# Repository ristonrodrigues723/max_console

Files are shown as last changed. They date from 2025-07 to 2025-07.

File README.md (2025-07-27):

This is my latest project: a Raspberry Pi Zero 2 W-based console running on RetroPie. I've optimized the Bill of Materials (BOM) to include the best and cheapest available items from official retailers for the Raspberry Pi and screen.
When overclocked(necessary for psp), this console should be able to emulate most systems, including Nintendo DS, Game Boy Advance (GBA), Game Boy Color (GBC), PlayStation (PSX), and even some (PSP games.
I am currently setting up the code for the buttons. My design incorporates 18-20 buttons, similar to a PSP, allowing for accurate emulation of those games. By utilizing the Adafruit button script for RetroPie, I anticipate being able to configure controls for most other consoles as well.
The touch functionality will be specifically for Nintendo DS emulation.

what makes it diff to others- i didnt use any expensive pi audio hats but a simple pam amplifier costing less than a dollar to get better audio thaen most,
i shaped it more like the psp the butten config and all there are the l1/l2 r1/r2 buttons on top of console likr the psp unlike most retro gaming consoles

already spemt 30+ hrs will ned to speand a total of  50+ hrs
## Combined Bill of Materials (BOM)

| Component Name | Quantity | Price (INR incl. GST) | Price (USD approx.) | Link | Status |
| :--- | :--- | :--- | :--- | :--- | :--- |
| High Quality Aluminium Heat Sink set for Raspberrypi | 1 | ₹41.30 | $0.49 | https://www.silverlineelectronics.in/products/copy-of-high-quality-copper-heatsink-for-raspberry-pi-4-3-zero-heavy-duty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 | Needed |
| HP MicroSD U1 TF Card 64GB | 1 | ₹470.00 | $5.62 | https://www.amazon.in/HP-MicroSD-U1-TF-Card-64GB/dp/B07DJGB43S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 | Needed |
| Raspberry Pi Zero 2W | 1 | ₹1,565.86 | $18.70 | https://www.silverlineelectronics.in/products/raspberry-pi-zero-2-silverline-india-authorised-distributor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 | Needed |
| Tactile Push Button Switch Assorted Kit - 25 Pieces pack | 1 | ₹149.00 | $1.78 | https://robocraze.com/products/tactile-push-button-switch-assorted-kit-25-pieces-pack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 | Needed |
| 3.5in Touch Screen LCD Display for Raspberry Pi | 1 | ₹911.00 | $10.87 | https://robocraze.com/products/3-5in-lcd-display-for-raspberry-pi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 | Needed |
| 4-Pins DIP Momentary Square Tactile Push Button Switch 10 Pieces - 6x6x5mm | 1 | ₹18.00 | $0.21 | https://robocraze.com/products/4-pins-dip-momentary-square-tactile-push-button-switch-10-pieces-6x6x5mm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 | Needed |
| 3.7V LiPo Batteries - BIS High Quality | 2 | ₹899.98 | $10.74 | https://thinkrobotics.com/products/bis-certified-3-7v-lipo-batteries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 | Needed |
| 2515 2 Pin JST XH Male Right Angle Connector – 2.54mm Pitch (25 Pcs) | 1 | ₹36.00 | $0.43 | https://roboticsdna.in/product/2515-2-pin-jst-xh-male-right-angle-connector-2-54mm-pitch-25-pcs/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{adgroup}&device=c&campaign={campaign}&adgroup={adgroup}&keyword=&matchtype=&gad_source=1&gad_campaignid=22411741198&gbraid=0AAAAAC-xzeGCjjNIR8MxcHx1pwcM04n0C&gclid=Cj0KCQjwhO3DBhDkARIsANxrhTpPnq3C8N-1qZAhaAwoMU_7-qtUxPFHU_YGlb16HUxtdIClyg2O6IaAkVuEALw_wcB | Needed |
| TP4056 Battery Charger C-Type Module with Protection | 1 | ₹19.00 | $0.23 | https://robocraze.com/products/tp4056-battery-charger-c-type-module-with-protection-1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 | Needed |
| MT3608 DC-DC Boost Module (2V-24V) | 1 | ₹44.00 | $0.53 | https://robocraze.com/products/mt3608-dc-dc-boost-module-2v-24v?_pos=2&_psq=boost&_ss=e&_v=1.0 | Needed |
| PAM8403 Digital Power Amplifier | 1 | ₹34.00 | $0.41 | https://robocraze.com/products/pam8403-digital-power-amplifier?_pos=1&_sid=4e256fde9&_ss=r | Needed |
| 2030 Cavity Speaker, 8Ω 2W | 1 | ₹300.00 | $3.59 | https://thinkrobotics.com/products/2030-cavity-speaker-8%CF%89-2w?_pos=2&_sid=e26492f4d&_ss=r | Needed |
| Solder Wire 50gm (1mm) | 1 | ₹100.00 | $1.20 | https://thinkrobotics.com/products/solder-wire-40gm-1 | Needed |
| PCB Fabrication (jlc) | 1 | ₹1,254.00 | $15.00 | *N/A (Service Cost)* | Needed |
| 3D Printing Services (printing legionm) | 1 | ₹585.20 | $7.00 | *N/A (Service Cost)* | Needed |
| UNI-T UT33D+ Digital Multi-meter | 1 | ₹875.00 | $10.47 | https://www.amazon.in/UNI-T-UT33D-Digital-Multi-meter-Manual/dp/B08W36VF6H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 | Needed |
| M3 10mm SS Screws (25 Pcs) | 1 | ₹83.60 | $1.00 | https://roboticsdna.in/product/m3-10mm-stainless-steel-screws-25-pieces/?src=google&kwd=&adgroup={adgroup}&device=c&campaign={campaign}&adgroup={adgroup}&keyword=&matchtype=&gad_source=1&gad_campaignid=22411741198&gbraid=0AAAAAC-xzeFYu4l4B2scm_19-MkV-ks1J&gclid=Cj0KCQjwkILEBhDeARIsAL--pjwVTMkqiyYBPgPZLET7SitmR4p4i6frF9hqcwMqjGWH6tK9m9Dq7pEaAnWKEALw_wcB | Needed |
| M3 Nuts SS (25 Pieces) | 1 | ₹35.40 | $0.42 | https://roboticsdna.in/product/m3-nuts-ss-25-pieces/?src=google&kwd=&adgroup={adgroup}&device=c&campaign={campaign}&adgroup={adgroup}&keyword=&matchtype=&gad_source=1&gad_campaignid=22411741198&gbraid=0AAAAAC-xzeHWsnFWhIbOm4RUnes1mhqz-&gclid=Cj0KCQjws4fEBhD-ARIsACC3d29MrUHuIXUFcil_X6_c8k6od2TpDrRg1q5CwJTiWuMUcHyvGuRSuj0aAh2yEALw_wcB | Needed |
| Hookup Wire (Stranded Assortment) | 1 | 84.00 | $1 | https://robocraze.com/products/single-stranded-hook-up-wires-1m-each-5-colors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| Needed |
| 0.1mm Copper Soldering Solder PPA Enamelled Repair Reel Wire | 1 | ₹25.00 | $0.30 | https://roboticsdna.in/product/0-1mm-copper-soldering-solder-ppa-enamelled-repair-reel-wire/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{adgroup}&device=c&campaign={campaign}&adgroup={adgroup}&keyword=&matchtype=&gad_source=1&gad_campaignid=22411741198&gbraid=0AAAAAC-xzeGXH678XaKVPbIhi9RKIVnVo&gclid=CjwKCAjw1ozEBhAdEiwAn9qbzd7ZAGkXTHaefr0acwciKOwB2wPFmYPZcgyTDhQEBKUefTSgr7LeAxoCFvQQAvD_BwE | Needed |
| 40x2 Female Berg Strip | 3 | ₹51.00 | $0.61 | https://robocraze.com/products/40x2-female-berg-strip?_pos=2&_psq=berg&_ss=e&_v=1.0 | Needed |
| 40x2 Pin 2.54mm Pitch Male Berg Strip | 3 | ₹27.00 | $0.32 | https://robocraze.com/products/40x2-pin-2-54mm-pitch-male-berg-strip?_pos=5&_psq=berg&_ss=e&_v=1.0 | Needed |
| Desoldering Wick | 2 | ₹28.00 | $0.33 | https://robocraze.com/products/desoldering-wick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 | Needed |
| Noel Soldering Flux Paste 10gm | 1 | ₹22.00 | $0.26 | https://robocraze.com/products/noel-soldering-flux-paste-10gm-pack-yellow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 | Needed |
| Heat Shrink Tubing | 6-7 | ₹0.00 | $0.00 | Owned/Pre-owned | Owned/Pre-owned |
| Desoldering Tool (Pump) | 1 | ₹0.00 | $0.00 | Owned/Pre-owned | Owned/Pre-owned |
| Soldering Iron | 1 | ₹0.00 | $0.00 | Owned/Pre-owned | Owned/Pre-owned |
| USB Cables-b and c | 2 | ₹0.00 | $0.00 | Owned/Pre-owned | Owned/Pre-owned |
| Precision Screwdrivers set | 1 | ₹0.00 | $0.00 | Owned/Pre-owned | Owned/Pre-owned |
| Multi-screwdriver | 1 | ₹0.00 | $0.00 | Owned/Pre-owned | Owned/Pre-owned |
| Hot Glue Gun and Glue Sticks | 1 | ₹0.00 | $0.00 | Owned/Pre-owned | Owned/Pre-owned |

---

### Additional Project Costs

| Item | Price (INR approx.) | Price (USD) | Status | Notes |
| :--- | :--- | :--- | :----- | :--- |
| Buffer for Price Increase/Stockout | ₹668.80 | $8.00 | Needed | damn currency conversion of 3percent charged by most retailers, if not woulfd be returned to hc |
| Shipping Fees | ₹250.80 | $3.00 | Needed | would be saved if not used and returned |

---

### Total Estimated Project Cost

| Currency | Amount |
| :--- | :----- |
| **INR** | **₹10,054.80** |
| **$USD** | **$119** |

---
if the rate of dollar to inr ids more the rest of money cold be returned to hc,
didnt recieve my raspi from raspapi ysws which gavr the participants local raspberrypi 0 2w , now it would have saved hc the price of that 0 2w no ides when i could get it .

some reatilers offer free shiping others still ask 1-2 dollars that the buffer for it
i didnt get thr raspi zero from old ysws , compeleted it could have saved hc some money but its still stuck in limbo

schematic

pcb-
2d-

3d pcb

case-


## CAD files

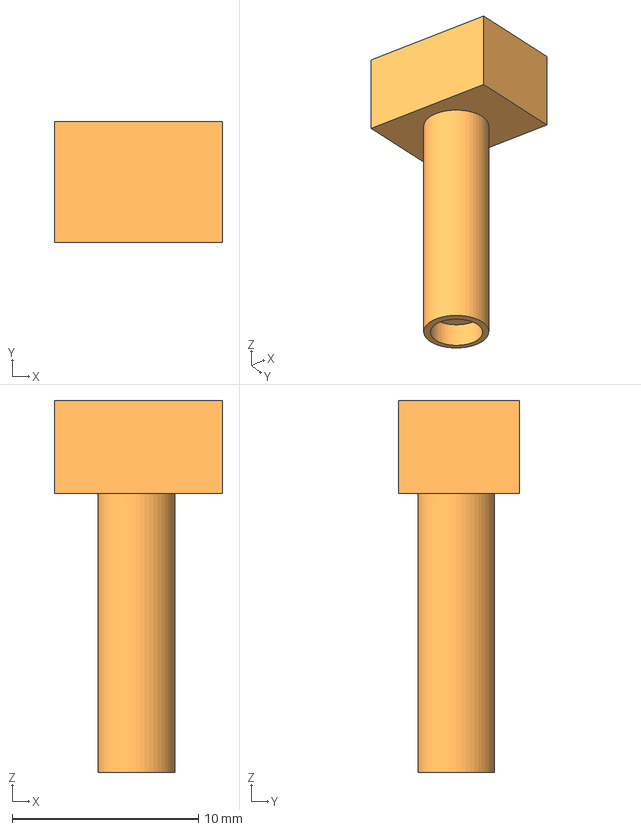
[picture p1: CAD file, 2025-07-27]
3d files/buttonsmall.step
9.04 x 6.50 x 20.0 mm

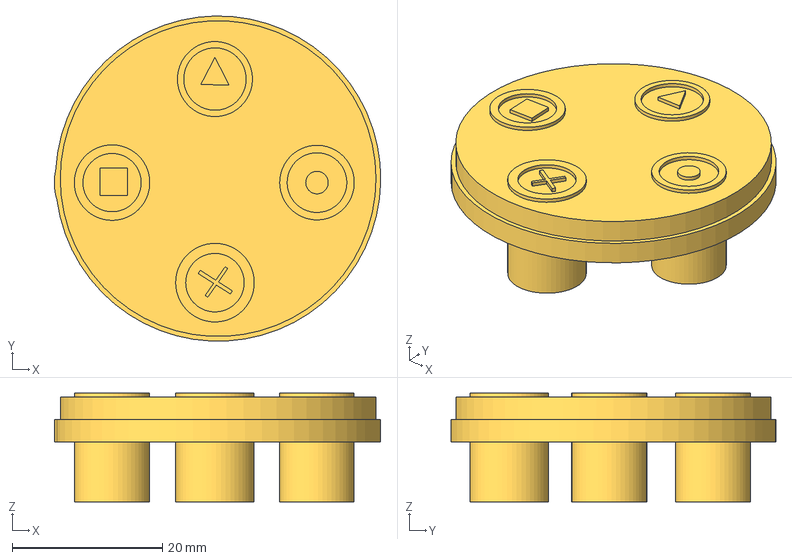
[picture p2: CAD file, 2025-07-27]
3d files/right pad.step
43.5 x 43.3 x 14.5 mm

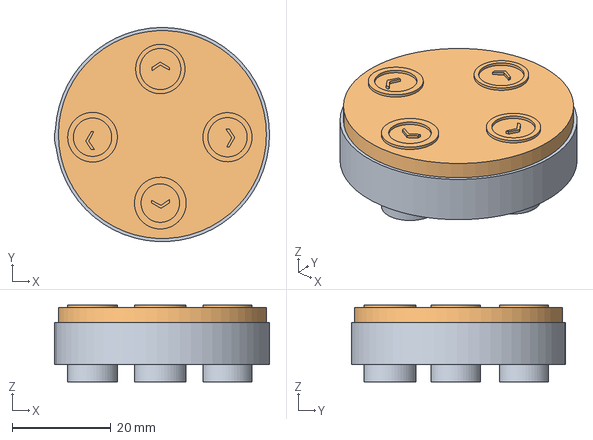
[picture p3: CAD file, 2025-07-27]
3d files/leftpad.step
43.5 x 43.3 x 15.5 mm

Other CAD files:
3d files/buttonsmall (1).step

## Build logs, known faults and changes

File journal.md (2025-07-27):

Title: Maximum retro console 
Author: Riston Rodrigues 
Description: this is a  a console running on raspi 02w running retopie which when overclocked should be able to emulate most old conslote games
waas entriely designed and done by me , includes amplifier and good speakers for immersive sound.
Created at: 27/7/25

what it does- adds better sound to the retro console using amplifier chip, sdesigned for psx psp games should un psp gsmes when pi is overclocked

Total time speant-30+ total time required -50hrs

cost of the project-120 dollars

day-18/7/25

i reserched and create d the bom as wekl the basic schematic on easyeda pro

added right tactile buttims 12 by 12 by 7.3 after considerations



right naming convenctions

right gnd connections to the d pad and face buttons-
so if i want to emulate psx i need 18 buttons aND adc chip which wont work with gba and snes

right wiring add resst of buttons-

14 pins added rightly-

wirinf got messed up-

added the raspi 3.5 inch scfreen it had no fot print has tri create customtook an hour 



i need to add the l 1l2 rf1 r2 on top as putting them on main pch makes no sense safter some reserch and work incan dividne use rigt angled headers to achievee the same

 now the top button panel will be cut and put on top like psp buttond ia bentg male headers



made right sdjustment it is 2 cm bif noe man just shouldnt get too ugly

time speant -6 hrs

day 2 19/7/25
task- exact placemtn of the components additonl button addition and placement , getting the dimensions right




added the place and made right adjustments for lcd plkacements

added the right dimensions and arrangd the components these need to be placed rightly to gibe it correctly feel manually adjusting the coordinates-


got the exact right dshape next task adding remaining buttons

was loing for attries and good barrries flat ones dont exkist most are cheap ripoffs cant use cylindrical as theyll mess up the most of things
will have to use 2 of 3.7V LiPo Batteries - BIS High Quality 20 it brings thr bil up by 10dollars
added the right routing both l1 l2 r1 r2 will be on top side by sidce will make the console more compact


ok new realizarion cant as the pi zero directly below the screen ading it belo the pcb will increae consile sixe woll ned to change placemntd

priblem make it compact vs longer

increased theight by a few cm cut its not that thick

time spent 5 hrs

day 3 20/7/25

adding the tppy4056 charging module boost converter battries placenmt , i reserched and theres no way i could place the raspi below 5he 3.5 inc lcb placing it on opp side of the board increases board height by 2-3 cm and it destryos compactnes compeletely so stuck what to do more
so i increased the length by 8 cm


 the module i think i shouls increase the body part rounf scre to make it symmetric

i addedte tp4056 , mt booster battderis pins to yhe schematic and pcb


connecte the charging and battery protectgion to sdpt to power on off then booster to the main circut.




corecting the c onnections


wired the correct rest home vol and hold butonds



coonnected reserched the pwm circut need to reroute some paths and tgings

rewired wire the pam

found added right speajkers
everything except the touch screen for nintendo consoles is done

time spent 5 hrs

day 5 23/7/25

tasks done added the righrt 134mil holes on 4 sides of pcb to fir ti in case
binded all 3d model as neded
now the task is crrating approprite case the budget is going above 100 bom is best optimized man hope it doesnt getr fckd too bad as the highway accc has no mony left



boolen 2 to smoothe render derived board****
shiftd jsxt to nbotom rerouted the nets and paths, fixed 6,, buttons


importrd correct model now cadsde design begins found 2-3 erroes in netlist-

really bad mirroring


 toip cover


the case upper part

addeed upper /lower case parts extrudes fot both usb-c top l1 ,l2 buttons
removed thr derived pcb to correct each indvivdaul sketch


fotgot yhr buttons

total time 8hrs

day 27/7/25
tasks-fixed the entire bom, added right links to bom, tored to find cheapest alternatives but the biggest problems id non acceptane og hcb and aliexpress doesnt dielever at my place

the buttons for the d pad and the o x A keys im did them




too slow lagginf on my old laptop

the button finishwed tge basic shaoe for that

the deriving cobsole didnt work- new thinga to dpo-

just too slow-
came to know that wculd hidce individcual patrs of cad many this savesso much time

extrusuin to match shell thcckness-


the other symbol pad finished-

finished thre right pd-

a problem with the derived sketchd as i try to get them thsurpress the below things they get messedup


finished d pad-




errors when i asembe the whols case gotta fix that

ok i exported the leftpad and right pad imported and problem solved



final assemblu unitl oi hey the board -

tatal time 5.5 hrs

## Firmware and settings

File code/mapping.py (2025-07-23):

#!/usr/bin/env python3 
#needs to added to raspi aftr retropie inatallation for getiing  to work 
# not tested tryar your own risk

import RPi.GPIO as GPIO
from evdev import UInput, ecodes
import time


GPIO.setmode(GPIO.BCM)



GPIO_MAPPING = {
    # D-Pad buttons for up down
    20: ecodes.KEY_DOWN,    # D-PadDown (gge8)- mapping i pcb and netizt
    21: ecodes.KEY_LEFT,    # D-PadLeft (gge9)
    24: ecodes.KEY_RIGHT,   # D-PadRight (gge7)
    16: ecodes.KEY_UP,      # D-PadUp (gge6)
    
    # Face buttons (Triangle, Circle, Cross, Square)
    19: ecodes.KEY_X,       # FaceButton△ (gge2) -> Mapped to 'X' key
    26: ecodes.KEY_A,       # FaceButton◯ (gge5) -> Mapped to 'A' key
 # thers a sort so 2-3 buttons will need canging
    0: ecodes.KEY_Z,        # FaceButton× (gge4) -> Mapped to 'Z' key
    
    6: ecodes.KEY_S,       # FaceButton□ (gge3) -> Mapped to 'S' key
    
   

    # Extra buttons - for psp emulation as per my pcb
    15: ecodes.KEY_E,       # Vol+ (gge15_3) -> Mapped to 'E' key
    22: ecodes.KEY_Q,       # Hold/Brightness (gge15_1) -> Mapped to 'Q' key
    23: ecodes.KEY_P,       # Vol- (gge15_2) -> Mapped to 'P' key
    14: ecodes.KEY_H,       # HOME (gge15_4) -> Mapped to 'H' key

    # Placeholder for Start & Select buttons_ the pcb gas errors these are reserved nned to be changed

    1: ecodes.KEY_ENTER,    # Start (gge14) -> Mapped to 'Enter' key
    2: ecodes.KEY_SPACE,    # Select (gge15) -> Mapped to 'Space' key
}

# gpo setup with pullup resistors
GPIO.setup(list(GPIO_MAPPING.keys()), GPIO.IN, pull_up_down=GPIO.PUD_UP)

 #virtauo keybard creattn and button mapping
capabilities = {ecodes.EV_KEY: list(GPIO_MAPPING.values())}
ui = UInput(capabilities, name="Pi Zero Gamepad")

# A function that handels presses releases
def handle_button_event(channel):
    key_code = GPIO_MAPPING.get(channel)
    if key_code:
        if GPIO.input(channel) == GPIO.LOW:  # Button press  gpio to gnd state
            ui.write(ecodes.EV_KEY, key_code, 1)  
            ui.syn()
        else:  # Button relesa dont mess 
            ui.write(ecodes.EV_KEY, key_code, 0)  
            ui.syn()

# Add event detection to all pins
for pin in GPIO_MAPPING.keys():
    GPIO.add_event_detect(pin, GPIO.BOTH, callback=handle_button_event, bouncetime=50)

try:
    print("GPIO button mapper script is running...")
   #loop that runs continusly
    while True:
        time.sleep(1)
        
except KeyboardInterrupt:
    print("\nExiting script.") #script exits
finally:
    ui.close()
    GPIO.cleanup()
